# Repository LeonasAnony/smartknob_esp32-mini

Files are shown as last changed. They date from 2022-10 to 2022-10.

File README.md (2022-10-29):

# SmartKnob



SmartKnob is an open-source input device with software-configurable endstops and virtual detents. Original by [Scott Bezek](https://github.com/scottbez1/smartknob).

A brushless gimbal motor is paired with a magnetic encoder to provide closed-loop torque feedback control, making it
possible to dynamically create and adjust the feel of detents and endstops.

# Modifications
- ESP32-S3-MINI-1N8
- 24x WS2812 20x20 LED
- SMD Resistor 4 direction Force Sensor
- Accelerometer

# Handheld Version
Handheld Mod in branch [handheld](https://github.com/LeonasAnony/smartknob_esp32-mini/tree/handheld)

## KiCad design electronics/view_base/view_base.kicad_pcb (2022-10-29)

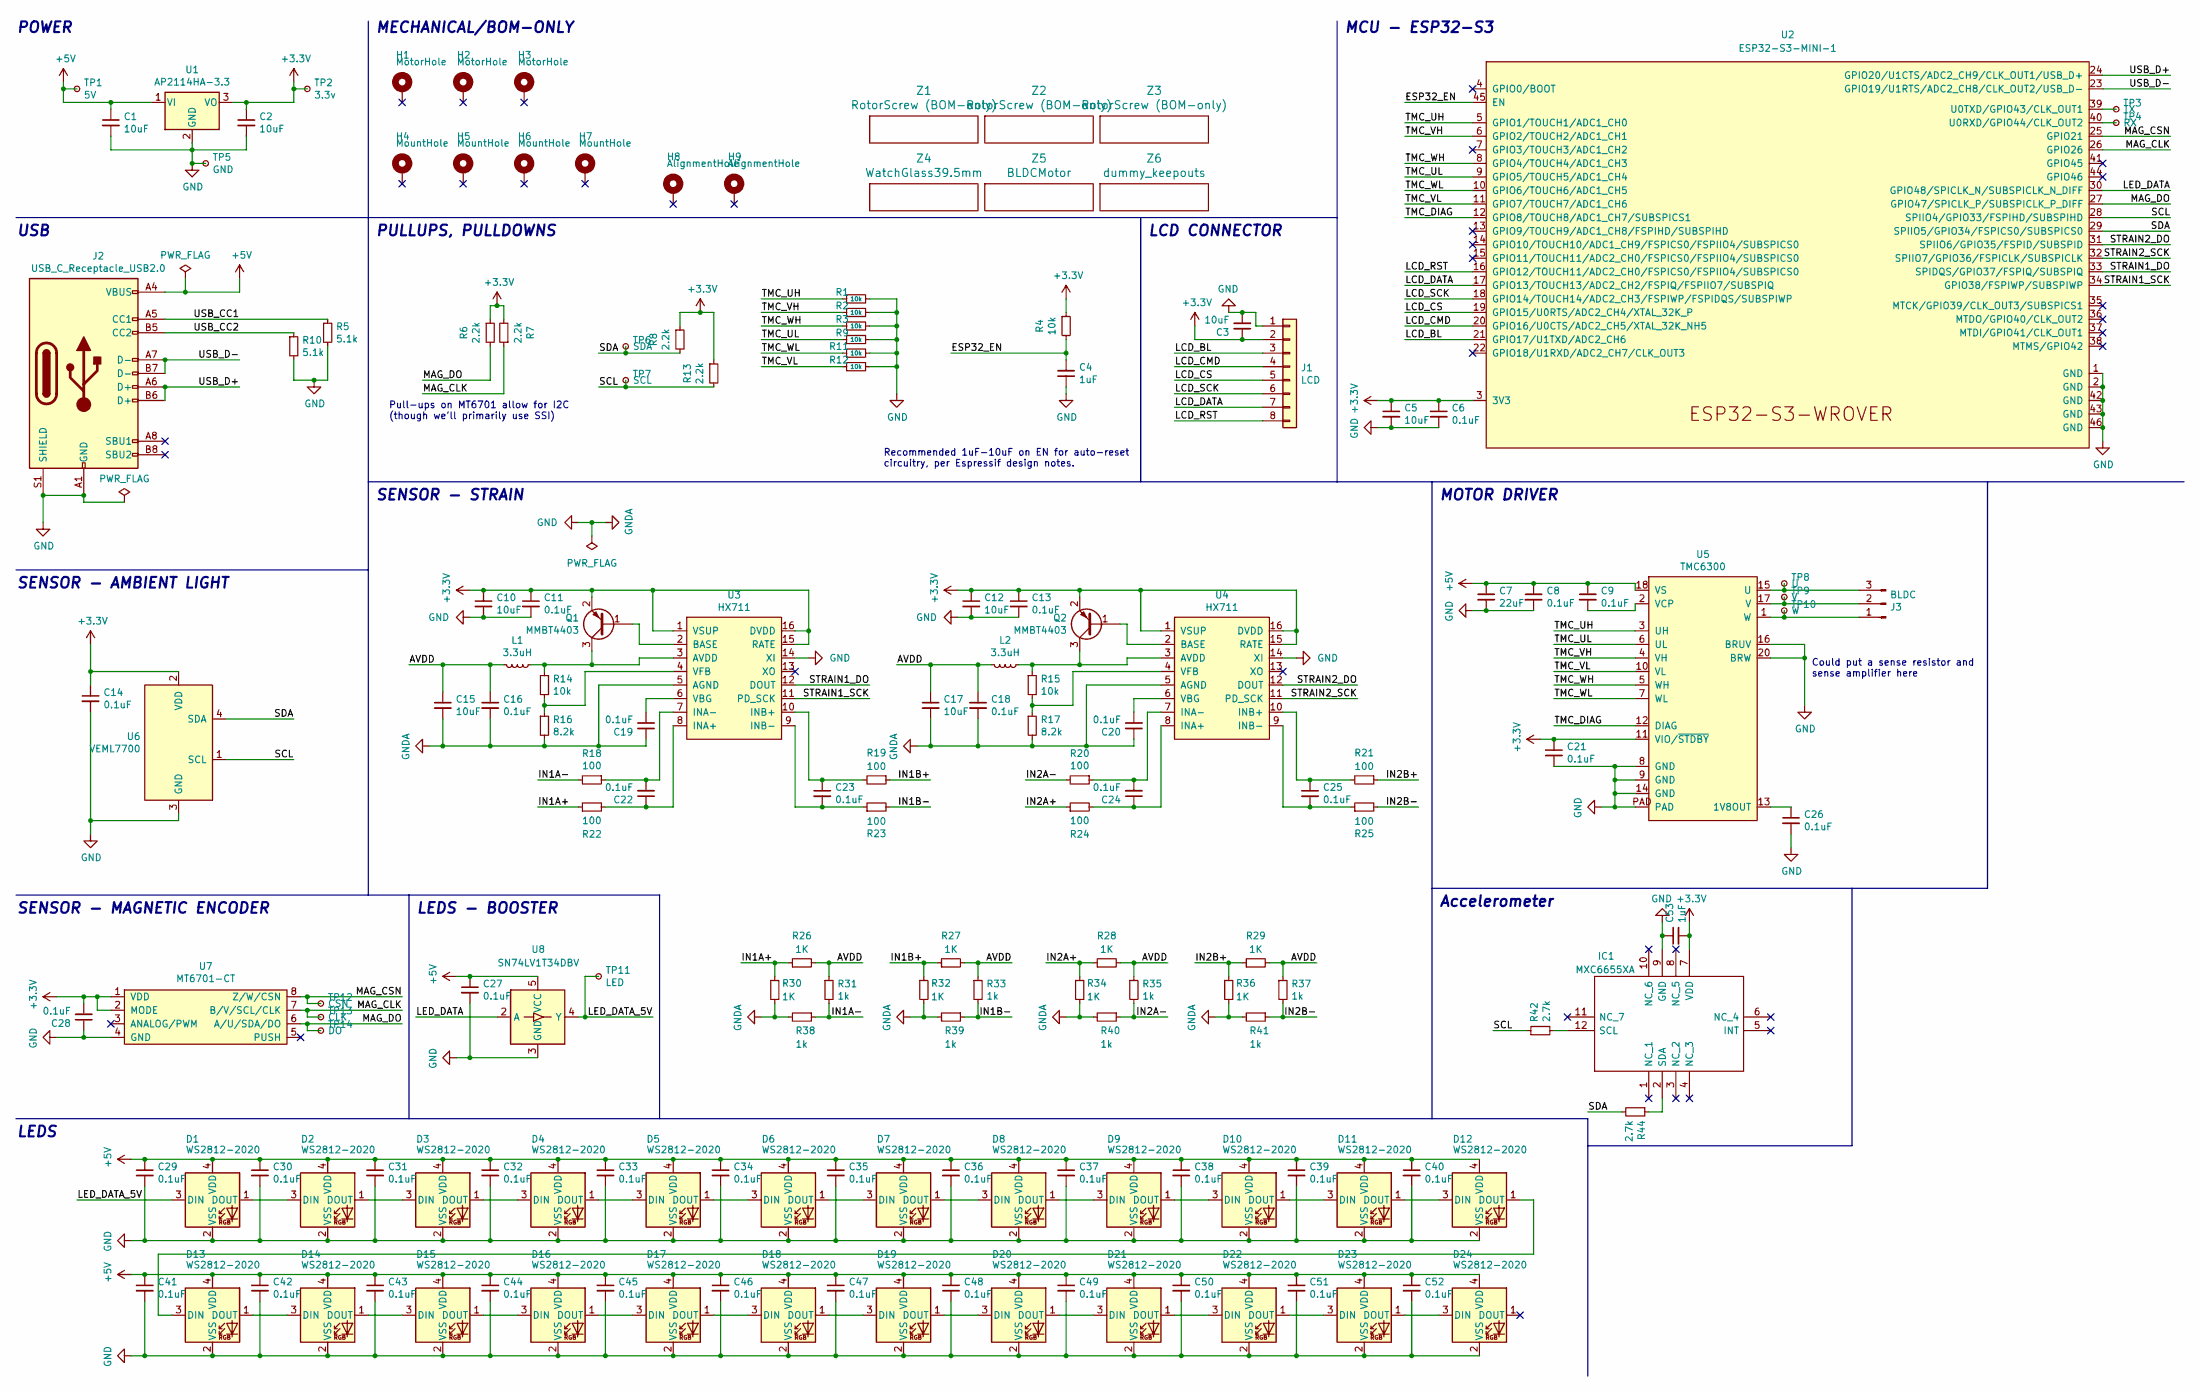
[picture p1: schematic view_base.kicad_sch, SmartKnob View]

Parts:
C1, C2, C3, C5, C10, C12, C15, C17: 10uF; C_0805_2012Metric; LCSC C2922480
C4: 1uF; C_0603_1608Metric; Mouser 187-CL10A105KA8NNNC
C6, C8, C9, C11, C13, C14, C16, C18, C19, C20, C21, C22, C23, C24, C25, C26, C27, C28, C29, C30, C31, C32, C33, C34, C35, C36, C37, C38, C39, C40, C41, C42, C43, C44, C45, C46, C47, C48, C49, C50, C51, C52: 0.1uF; C_0603_1608Metric; LCSC C1591
C7: 22uF; C_0805_2012Metric; LCSC C98190
C53: 1uF; C_0603_1608Metric; LCSC C1591
D1, D2, D3, D4, D5, D6, D7, D8, D9, D10, D11, D12, D13, D14, D15, D16, D17, D18, D19, D20, D21, D22, D23, D24: WS2812-2020; Digikey 1528-4691-ND
H1, H2, H3: MotorHole; MountingHole_M1.6
H4, H5, H6, H7: MountHole; MountingHole_2.2mm_M2_ISO7380_Pad_NonVirtual
H8, H9: AlignmentHole; MountingHole_2.2mm_M2_ISO7380_Pad_NonVirtual
IC1: MXC6655XA; Mouser Part Number 438-MXC6655XA
J1: LCD; SolderPads_2mm_8
J2: USB_C_Receptacle_USB2.0; USB4510_NoPaste; LCSC C428463
J3: BLDC; 532610371; LCSC C293630
L1, L2: 3.3uH; L_0805_2012Metric; LCSC C307744
Q1, Q2: MMBT4403; SOT-23; LCSC C78864
R1, R2, R3, R4, R9, R11, R12, R14, R15: 10k; R_0603_1608Metric; LCSC C98220
R5, R10: 5.1k; R_0603_1608Metric; LCSC C105580
R6, R7, R8, R13: 2.2k; R_0603_1608Metric; LCSC C4190
R16, R17: 8.2k; R_0603_1608Metric; LCSC C114637
R18, R19, R20, R21, R22, R23, R24, R25: 100; R_0603_1608Metric; LCSC C319953
R26, R27, R28, R29, R30, R32, R34, R36: 1K; R_2512_6332Metric
R31, R33, R35, R37, R38, R39, R40, R41: 1k; R_0603_1608Metric; LCSC C98220
R42, R44: 2.7k; R_0603_1608Metric; LCSC C98220
TP1: 5V; TestPoint_Pad_D2.0mm_ValueSilk
TP2: 3.3v; TestPoint_Pad_D2.0mm_ValueSilk
TP3: TX; TestPoint_Pad_D2.0mm_ValueSilk
TP4: RX; TestPoint_Pad_D2.0mm_ValueSilk
TP5: GND; TestPoint_Pad_D2.0mm_ValueSilk
TP6: SDA; TestPoint_Pad_D2.0mm_ValueSilk
TP7: SCL; TestPoint_Pad_D2.0mm_ValueSilk
TP8: U; TestPoint_Pad_D2.0mm_ValueSilk
TP9: V; TestPoint_Pad_D2.0mm_ValueSilk
TP10: W; TestPoint_Pad_D2.0mm_ValueSilk
TP11: LED; TestPoint_Pad_D2.0mm_ValueSilk
TP12: CSN; TestPoint_Pad_D2.0mm_ValueSilk
TP13: CLK; TestPoint_Pad_D2.0mm_ValueSilk
TP14: DO; TestPoint_Pad_D2.0mm_ValueSilk
U1: AP2114HA-3.3; SOT-223-3_TabPin2; LCSC C460314
U2: ESP32-S3-MINI-1
U3, U4: HX711; SOIC-16_3.9x9.9mm_P1.27mm; LCSC C43656
U5: TMC6300; QFN-20-1EP_3x3mm_P0.4mm_EP1.65x1.65mm_ThermalVias_LargerVia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; Digikey TMC6300-LA-T
U6: VEML7700; VEML7700-TOP; Digikey VEML7700-TT
U7: MT6701-CT; SOIC-8_3.9x4.9mm_P1.27mm; LCSC C2856764
U8: SN74LV1T34DBV; SOT-23-5; LCSC C100024
Z1, Z2, Z3: RotorScrew (BOM-only); bom_only_no_pin
Z4: WatchGlass39.5mm; bom_only_no_pin
Z5: BLDCMotor; bom_only_no_pin
Z6: dummy_keepouts; ViewKeepouts3d

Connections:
+3V3: C2.1, C3.1, C5.1, C6.1, C10.1, C11.1, C12.1, C13.1, C14.1, C21.1, C28.2, C53.2, IC1.7 (VDD), J1.2, Q1.2 (E), Q2.2 (E), R4.1, R6.1, R7.2, R8.1, R13.1, TP2.1, U1.3 (VO), U2.3 (3V3), U3.1 (VSUP), U3.15 (RATE), U3.16 (DVDD), U4.1 (VSUP), U4.15 (RATE), U4.16 (DVDD), U5.11 (VIO/~STDBY), U6.2 (VDD), U7.1 (VDD), U7.2 (MODE)
+5V: C1.1, C7.1, C8.1, C9.1, C27.1, C29.1, C30.1, C31.1, C32.1, C33.1, C34.1, C35.1, C36.1, C37.1, C38.1, C39.1, C40.1, C41.1, C42.1, C43.1, C44.1, C45.1, C46.1, C47.1, C48.1, C49.1, C50.1, C51.1, C52.1, D1.4 (VDD), D2.4 (VDD), D3.4 (VDD), D4.4 (VDD), D5.4 (VDD), D6.4 (VDD), D7.4 (VDD), D8.4 (VDD), D9.4 (VDD), D10.4 (VDD), D11.4 (VDD), D12.4 (VDD), D13.4 (VDD), D14.4 (VDD), D15.4 (VDD), D16.4 (VDD), D17.4 (VDD), D18.4 (VDD), D19.4 (VDD), D20.4 (VDD), D21.4 (VDD), D22.4 (VDD), D23.4 (VDD), D24.4 (VDD), J2.A4 (VBUS), J2.A9 (VBUS), J2.B4 (VBUS), J2.B9 (VBUS), TP1.1, U1.1 (VI), U5.18 (VS), U8.5 (VCC)
/ESP32_EN: C4.1, R4.2, U2.45 (EN)
/IN1A+: R22.1, R26.1, R30.1
/IN1A-: R18.2, R31.2, R38.1
/IN1B+: R19.1, R27.1, R32.1
/IN1B-: R23.2, R33.2, R39.1
/IN2A+: R24.1, R28.1, R34.1
/IN2A-: R20.2, R35.2, R40.1
/IN2B+: R21.1, R29.1, R36.1
/LCD_BL: J1.3, U2.21 (GPIO17/U1TXD/ADC2_CH6)
/LCD_CMD: J1.4, U2.20 (GPIO16/U0CTS/ADC2_CH5/XTAL_32K_NH5)
/LCD_CS: J1.5, U2.19 (GPIO15/U0RTS/ADC2_CH4/XTAL_32K_P)
/LCD_DATA: J1.7, U2.17 (GPIO13/TOUCH13/ADC2_CH2/FSPIQ/FSPIIO7/S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)
/LCD_RST: J1.8, U2.16 (GPIO12/TOUCH11/ADC2_CH0/FSPICS0/FSPIIO4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)
/LCD_SCK: J1.6, U2.18 (GPIO14/TOUCH14/ADC2_CH3/FSPIWP/FSPIDQS/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)
/LED_DATA: U2.30 (GPIO48/SPICLK_N/SUBSPICLK_N_DIFF), U8.2 (A)
/LED_DATA_5V: D1.3 (DIN), TP11.1, U8.4 (Y)
/MAG_CLK: R7.1, TP13.1, U2.26 (GPIO26), U7.7 (B/V/SCL/CLK)
/MAG_CSN: TP12.1, U2.25 (GPIO21), U7.8 (Z/W/CSN)
/MAG_DO: R6.2, TP14.1, U2.27 (GPIO47/SPICLK_P/SUBSPICLK_P_DIFF), U7.6 (A/U/SDA/DO)
/SCL: R13.2, R42.1, TP7.1, U2.28 (SPIIO4/GPIO33/FSPIHD/SUBSPIHD), U6.1 (SCL)
/SDA: R8.2, R44.2, TP6.1, U2.29 (SPIIO5/GPIO34/FSPICS0/SUBSPICS0), U6.4 (SDA)
/STRAIN1_DO: U2.33 (SPIDQS/GPIO37/FSPIQ/SUBSPIQ), U3.12 (DOUT)
/STRAIN1_SCK: U2.34 (GPIO38/FSPIWP/SUBSPIWP), U3.11 (PD_SCK)
/STRAIN2_DO: U2.31 (SPIIO6/GPIO35/FSPID/SUBSPID), U4.12 (DOUT)
/STRAIN2_SCK: U2.32 (SPIIO7/GPIO36/FSPICLK/SUBSPICLK), U4.11 (PD_SCK)
/TMC_DIAG: U2.12 (GPIO8/TOUCH8/ADC1_CH7/SUBSPICS1), U5.12 (DIAG)
/TMC_UH: R1.1, U2.5 (GPIO1/TOUCH1/ADC1_CH0), U5.3 (UH)
/TMC_UL: R9.1, U2.9 (GPIO5/TOUCH5/ADC1_CH4), U5.6 (UL)
/TMC_VH: R2.1, U2.6 (GPIO2/TOUCH2/ADC1_CH1), U5.4 (VH)
/TMC_VL: R12.1, U2.11 (GPIO7/TOUCH7/ADC1_CH6), U5.10 (VL)
/TMC_WH: R3.1, U2.8 (GPIO4/TOUCH4/ADC1_CH3), U5.5 (WH)
/TMC_WL: R11.1, U2.10 (GPIO6/TOUCH6/ADC1_CH5), U5.7 (WL)
/USB_CC1: J2.A5 (CC1), R5.1
/USB_CC2: J2.B5 (CC2), R10.1
/USB_D+: J2.A6 (D+), J2.B6 (D+), U2.24 (GPIO20/U1CTS/ADC2_CH9/CLK_OUT1/USB_D+)
/USB_D-: J2.A7 (D-), J2.B7 (D-), U2.23 (GPIO19/U1RTS/ADC2_CH8/CLK_OUT2/USB_D-)
GND: C1.2, C2.2, C3.2, C4.2, C5.2, C6.2, C7.2, C8.2, C10.2, C11.2, C12.2, C13.2, C14.2, C15.2, C16.2, C17.2, C18.2, C19.1, C20.1, C21.2, C26.2, C27.2, C28.1, C29.2, C30.2, C31.2, C32.2, C33.2, C34.2, C35.2, C36.2, C37.2, C38.2, C39.2, C40.2, C41.2, C42.2, C43.2, C44.2, C45.2, C46.2, C47.2, C48.2, C49.2, C50.2, C51.2, C52.2, C53.1, D1.2 (VSS), D2.2 (VSS), D3.2 (VSS), D4.2 (VSS), D5.2 (VSS), D6.2 (VSS), D7.2 (VSS), D8.2 (VSS), D9.2 (VSS), D10.2 (VSS), D11.2 (VSS), D12.2 (VSS), D13.2 (VSS), D14.2 (VSS), D15.2 (VSS), D16.2 (VSS), D17.2 (VSS), D18.2 (VSS), D19.2 (VSS), D20.2 (VSS), D21.2 (VSS), D22.2 (VSS), D23.2 (VSS), D24.2 (VSS), IC1.9 (GND), J1.1, J2.A1 (GND), J2.A12 (GND), J2.B1 (GND), J2.B12 (GND), J2.S1 (SHIELD), R1.2, R2.2, R3.2, R5.2, R9.2, R10.2, R11.2, R12.2, R16.2, R17.2, R30.2, R32.2, R34.2, R36.2, R38.2, R39.2, R40.2, R41.2, TP5.1, U1.2 (GND), U2.1 (GND), U2.2 (GND), U2.42 (GND), U2.43 (GND), U2.46 (GND), U3.5 (AGND), U3.14 (XI), U4.5 (AGND), U4.14 (XI), U5.8 (GND), U5.9 (GND), U5.14 (GND), U5.16 (BRUV), U5.20 (BRW), U5.PAD, U6.3 (GND), U7.4 (GND), U8.3 (GND)
unnamed: C9.2, U5.2 (VCP)
unnamed: C19.2, U3.6 (VBG)
unnamed: C20.2, U4.6 (VBG)
unnamed: C22.1, R22.2, U3.8 (INA+)
unnamed: C22.2, R18.1, U3.7 (INA-)
unnamed: C23.1, R19.2, U3.10 (INB+)
unnamed: C23.2, R23.1, U3.9 (INB-)
unnamed: C24.1, R24.2, U4.8 (INA+)
unnamed: C24.2, R20.1, U4.7 (INA-)
unnamed: C25.1, R21.2, U4.10 (INB+)
unnamed: C25.2, R25.1, U4.9 (INB-)
unnamed: C26.1, U5.13 (1V8OUT)
unnamed: D1.1 (DOUT), D2.3 (DIN)
unnamed: D2.1 (DOUT), D3.3 (DIN)
unnamed: D3.1 (DOUT), D4.3 (DIN)
unnamed: D4.1 (DOUT), D5.3 (DIN)
unnamed: D5.1 (DOUT), D6.3 (DIN)
unnamed: D6.1 (DOUT), D7.3 (DIN)
unnamed: D7.1 (DOUT), D8.3 (DIN)
unnamed: D8.1 (DOUT), D9.3 (DIN)
unnamed: D10.1 (DOUT), D11.3 (DIN)
unnamed: D9.1 (DOUT), D10.3 (DIN)
unnamed: D11.1 (DOUT), D12.3 (DIN)
unnamed: D12.1 (DOUT), D13.3 (DIN)
unnamed: D13.1 (DOUT), D14.3 (DIN)
unnamed: D14.1 (DOUT), D15.3 (DIN)
unnamed: D15.1 (DOUT), D16.3 (DIN)
unnamed: D16.1 (DOUT), D17.3 (DIN)
unnamed: D17.1 (DOUT), D18.3 (DIN)
unnamed: D18.1 (DOUT), D19.3 (DIN)
unnamed: D19.1 (DOUT), D20.3 (DIN)
unnamed: D20.1 (DOUT), D21.3 (DIN)
unnamed: D21.1 (DOUT), D22.3 (DIN)
unnamed: D22.1 (DOUT), D23.3 (DIN)
unnamed: D23.1 (DOUT), D24.3 (DIN)
unnamed: IC1.2 (SDA), R44.1
unnamed: IC1.12 (SCL), R42.2
unnamed: J3.1, TP10.1, U5.1 (W)
unnamed: J3.2, TP9.1, U5.17 (V)
unnamed: J3.3, TP8.1, U5.15 (U)
unnamed: L1.1, Q1.3 (C), R14.1, U3.3 (AVDD)
unnamed: L2.1, Q2.3 (C), R15.1, U4.3 (AVDD)
unnamed: Q1.1 (B), U3.2 (BASE)
unnamed: Q2.1 (B), U4.2 (BASE)
unnamed: R14.2, R16.1, U3.4 (VFB)
unnamed: R15.2, R17.1, U4.4 (VFB)
unnamed: TP3.1, U2.39 (U0TXD/GPIO43/CLK_OUT1)
unnamed: TP4.1, U2.40 (U0RXD/GPIO44/CLK_OUT2)

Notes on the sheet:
SENSOR - STRAIN
MECHANICAL/BOM-ONLY
Accelerometer
MCU - ESP32-S3
LEDS
PULLUPS, PULLDOWNS
Could put a sense resistor and sense amplifier here
MOTOR DRIVER
Recommended 1uF-10uF on EN for auto-reset circuitry, per Espressif design notes.
POWER
SENSOR - AMBIENT LIGHT
LEDS - BOOSTER
SENSOR - MAGNETIC ENCODER
Pull-ups on MT6701 allow for I2C (though we'll primarily use SSI)
USB
LCD CONNECTOR

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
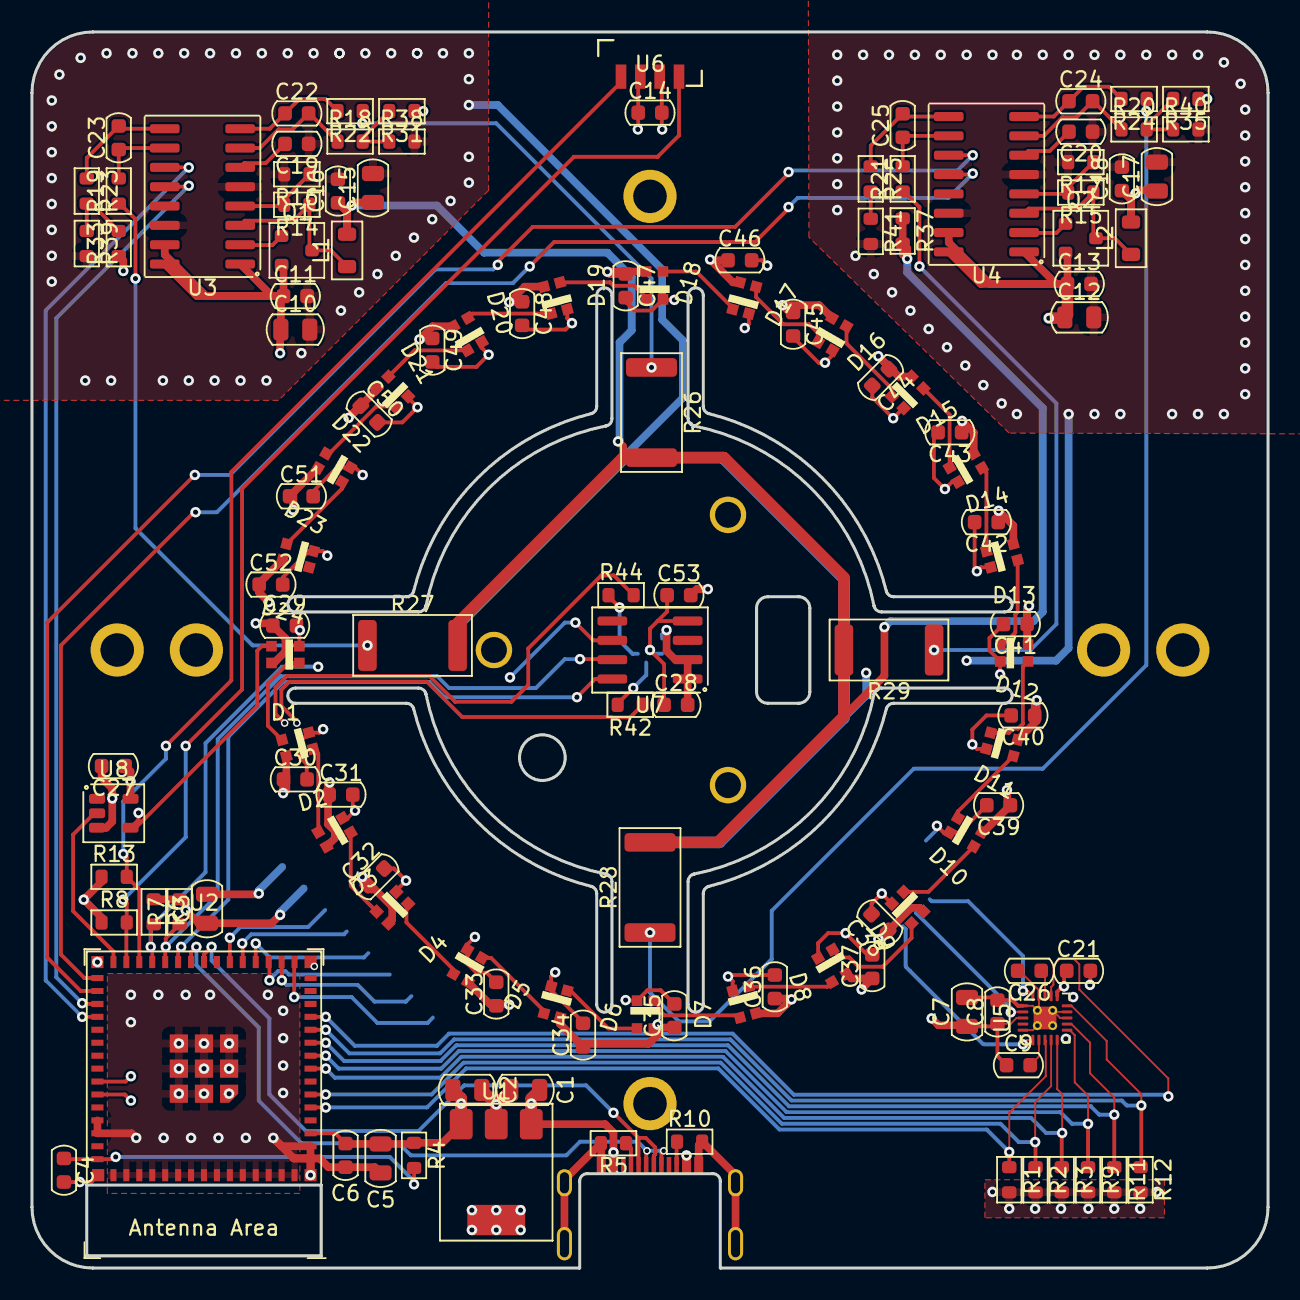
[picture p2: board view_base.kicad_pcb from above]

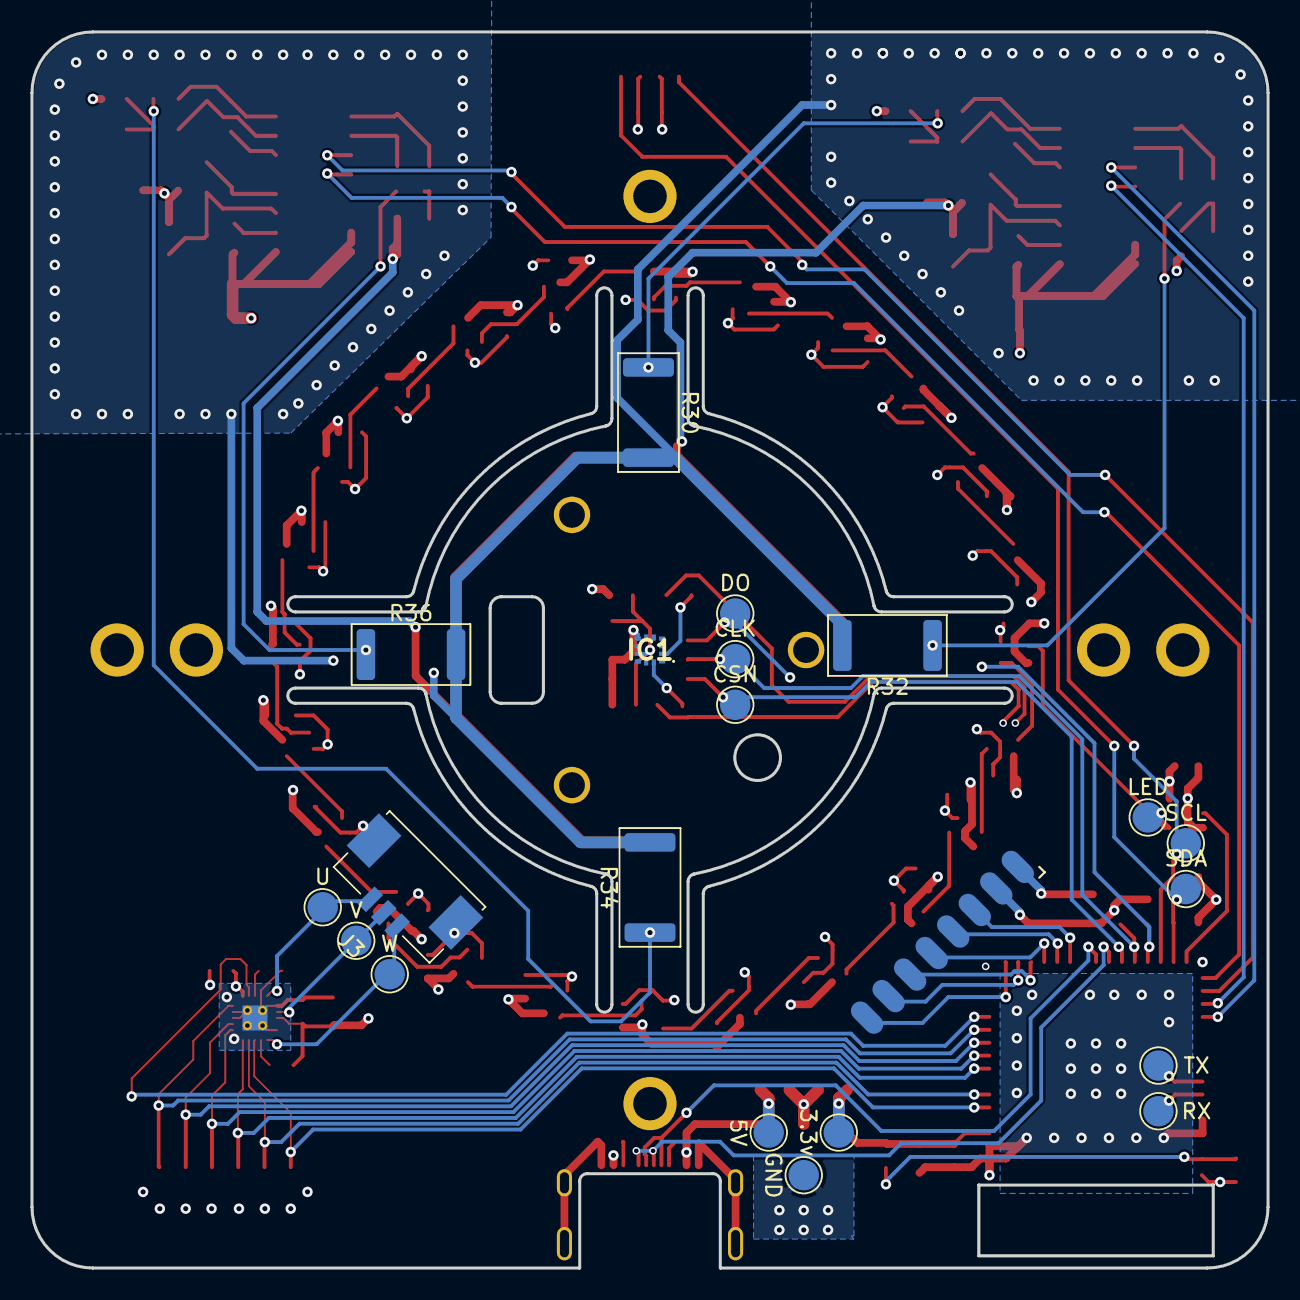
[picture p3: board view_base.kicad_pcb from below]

Board: 4 copper layers, 81.2 x 81.2 mm, 165 parts (21 on the bottom side), 89 nets.

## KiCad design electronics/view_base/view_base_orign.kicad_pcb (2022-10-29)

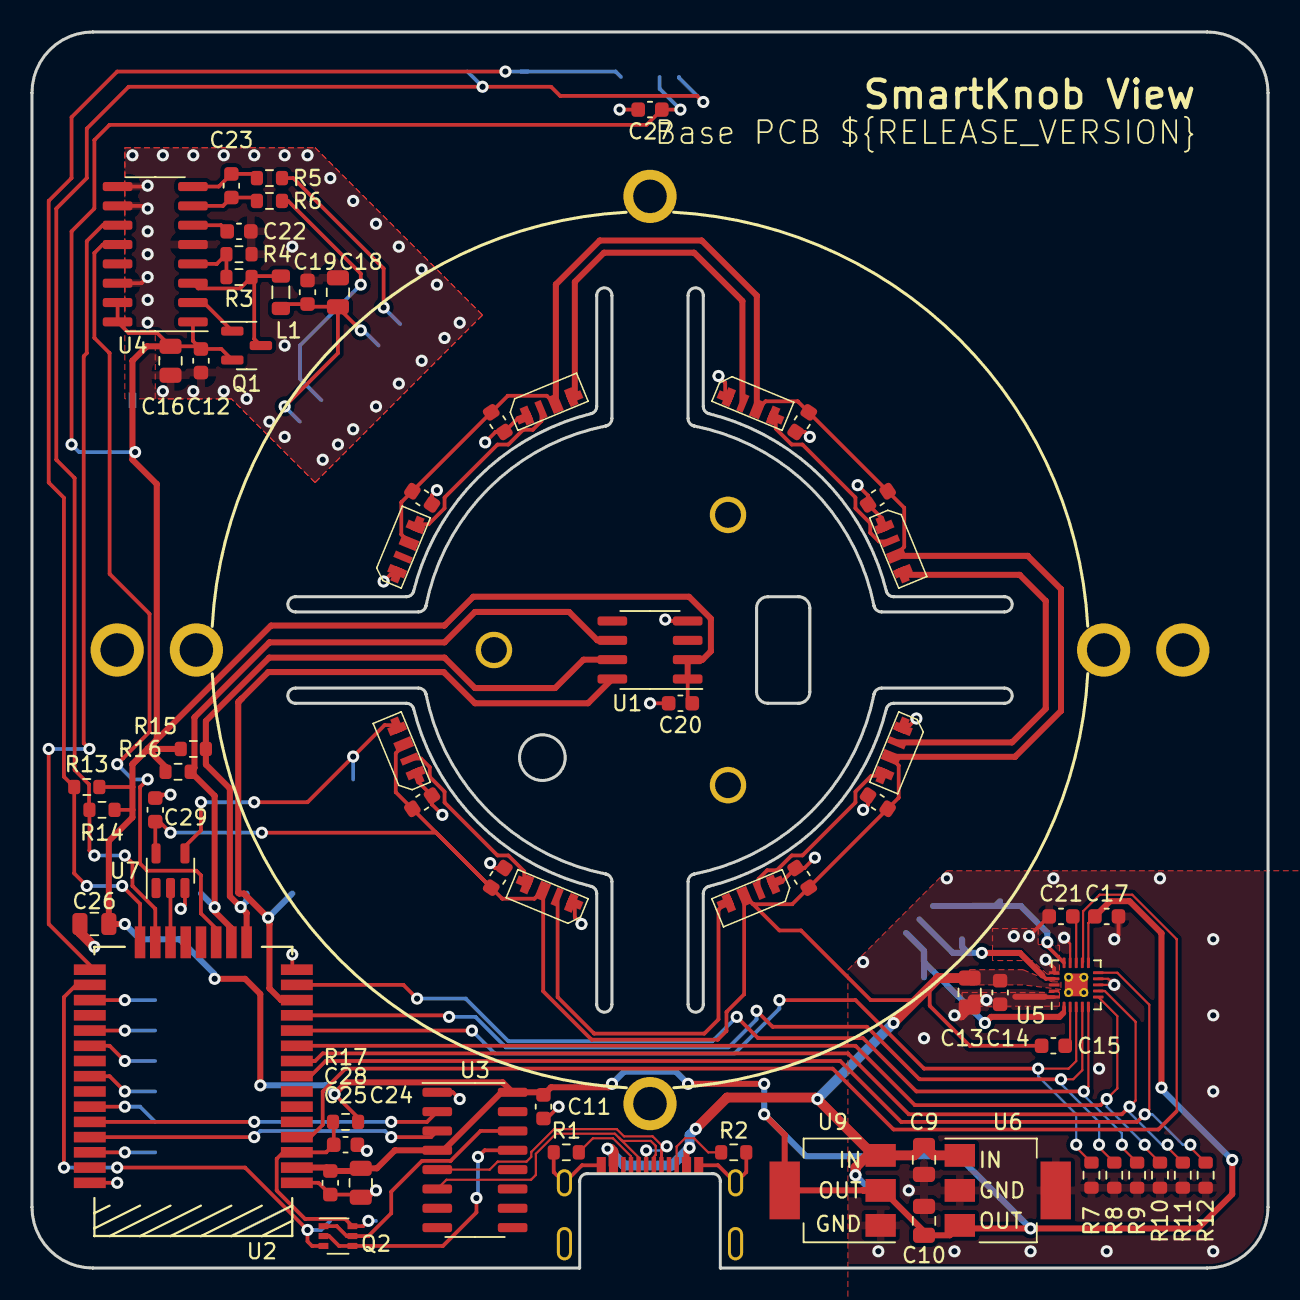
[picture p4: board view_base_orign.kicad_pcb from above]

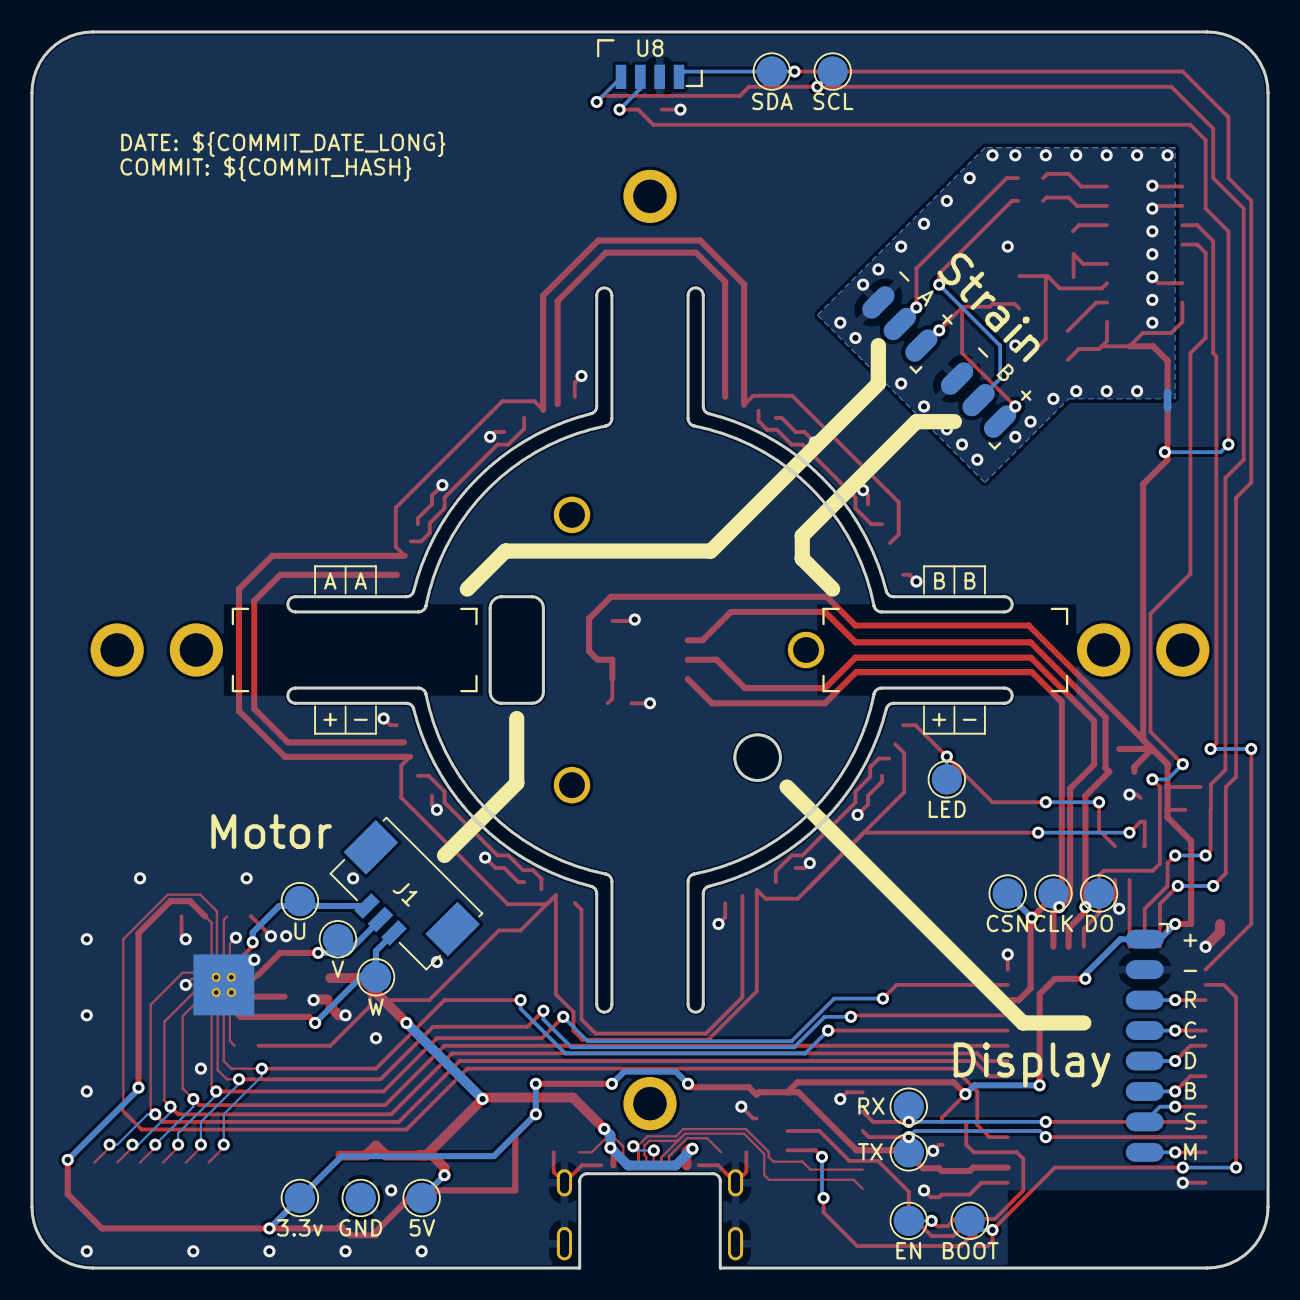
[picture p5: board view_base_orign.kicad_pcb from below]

Board: 2 copper layers, 81.2 x 81.2 mm, 107 parts (26 on the bottom side), 57 nets.

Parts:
C1, C2, C3, C4, C5, C6, C7, C8, C11, C12, C14, C15, C17, C19, C20, C21, C22, C23, C25, C27, C29: 0.1uF; C_0603_1608Metric
C9, C10, C16, C18, C24, C26: 10uF; C_0805_2012Metric
C13: 22uF; C_0805_2012Metric
C28: 1uF; C_0603_1608Metric
D1, D2, D3, D4, D5, D6, D7, D8: SK6812SIDE-A; SK6812-SIDE-A
H1, H2, H3: MotorHole; MountingHole_M1.6
H4, H5, H6, H7: MountHole; MountingHole_2.2mm_M2_ISO7380_Pad_NonVirtual
H8, H9: AlignmentHole; MountingHole_2.2mm_M2_ISO7380_Pad_NonVirtual
J1: BLDC; 532610371
J2: USB_C_Receptacle_USB2.0; USB4510_NoPaste
J3: LCD; SolderPads_2mm_8
J4: A; SolderPads_2mm_3_STRAIN
J5: B; SolderPads_2mm_3_STRAIN
L1: 3.3uH; L_0805_2012Metric
NT1: NetTie_2; NetTie-2_SMD_Pad0.5mm
Q1: MMBT4403; SOT-23
Q2: UMH3N; SOT-363_SC-70-6
R1, R2: 5.1k; R_0603_1608Metric
R3, R7, R8, R9, R10, R11, R12, R17: 10k; R_0603_1608Metric
R4: 8.2k; R_0603_1608Metric
R5, R6: 100; R_0603_1608Metric
R13, R14, R15, R16: 2.2k; R_0603_1608Metric
TP1: 5V; TestPoint_Pad_D2.0mm_ValueSilk
TP2: 3.3v; TestPoint_Pad_D2.0mm_ValueSilk
TP3: GND; TestPoint_Pad_D2.0mm_ValueSilk
TP4: SDA; TestPoint_Pad_D2.0mm_ValueSilk
TP5: SCL; TestPoint_Pad_D2.0mm_ValueSilk
TP6: U; TestPoint_Pad_D2.0mm_ValueSilk
TP7: V; TestPoint_Pad_D2.0mm_ValueSilk
TP8: W; TestPoint_Pad_D2.0mm_ValueSilk
TP9: CSN; TestPoint_Pad_D2.0mm_ValueSilk
TP10: CLK; TestPoint_Pad_D2.0mm_ValueSilk
TP11: DO; TestPoint_Pad_D2.0mm_ValueSilk
TP12: LED; TestPoint_Pad_D2.0mm_ValueSilk
TP13: EN; TestPoint_Pad_D2.0mm_ValueSilk
TP14: BOOT; TestPoint_Pad_D2.0mm_ValueSilk
TP15: TX; TestPoint_Pad_D2.0mm_ValueSilk
TP16: RX; TestPoint_Pad_D2.0mm_ValueSilk
U1: MT6701-CT; SOIC-8_3.9x4.9mm_P1.27mm
U2: T-Micro32_Plus; T-Micro32
U3: CH340C; SOIC-16_3.9x9.9mm_P1.27mm
U4: HX711; SOIC-16_3.9x9.9mm_P1.27mm
U5: TMC6300; QFN-20-1EP_3x3mm_P0.4mm_EP1.65x1.65mm_ThermalVias_LargerVia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
U6: AP2114HA-3.3; SOT-223-3_TabPin2_InGndOut
U7: SN74LV1T34DBV; SOT-23-5
U8: VEML7700; VEML7700-TOP
U9: TS1117BCW33_RPG; SOT-223-3_TabPin2_GndOutIn
Z1, Z2, Z3, Z4: BF350-3AA Strain Gauge; BF350-3AA
Z5: dummy_keepouts; ViewKeepouts3d
Z6, Z7, Z8: RotorScrew (BOM-only); bom_only_no_pin
Z9: WatchGlass39.5mm; bom_only_no_pin
Z10: BLDCMotor; bom_only_no_pin

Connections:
+3V3: C10.1, C11.1, C12.1, C16.1, C17.1, C20.1, C24.1, C25.1, C26.1, C27.1, J3.1, Q1.2 (E), R13.1, R14.1, R15.1, R16.2, R17.1, TP2.1, U1.1 (VDD), U1.2 (MODE), U2.2 (3V3), U3.4 (V3), U3.16 (VCC), U4.1 (VSUP), U4.15 (RATE), U4.16 (DVDD), U5.11 (VIO/~STDBY), U6.3 (VO), U8.2 (VDD), U9.2 (Output)
+5V: C1.1, C2.1, C3.1, C4.1, C5.1, C6.1, C7.1, C8.1, C9.1, C13.1, C14.1, C15.1, C29.1, D1.2 (VDD), D2.2 (VDD), D3.2 (VDD), D4.2 (VDD), D5.2 (VDD), D6.2 (VDD), D7.2 (VDD), D8.2 (VDD), J2.A4 (VBUS), J2.A9 (VBUS), J2.B4 (VBUS), J2.B9 (VBUS), TP1.1, U5.18 (VS), U6.1 (VI), U7.5 (VCC), U9.3 (Input)
/DTR: Q2.2 (B1), Q2.4 (E2), U3.13 (~DTR)
/ESP32_BOOT: Q2.3 (C2), TP14.1, U2.25 (IO0)
/ESP32_EN: C28.1, Q2.6 (C1), R17.2, TP13.1, U2.3 (EN)
/LCD_BACKLIGHT: J3.6, U2.31 (IO19)
/LCD_CMD: J3.8, U2.36 (IO22)
/LCD_CS: J3.7, U2.33 (IO21)
/LCD_DATA: J3.5, U2.29 (IO5)
/LCD_RST: J3.3, U2.26 (IO4)
/LCD_SCK: J3.4, U2.28 (IO20)
/LED_DATA_3V3: U2.21 (IO7), U7.2 (A)
/LED_DATA_5V: D1.1 (DIN), TP12.1, U7.4 (Y)
/MAG_CLK: R16.1, TP10.1, U1.7 (B/V/SCL/CLK), U2.16 (IO13)
/MAG_CSN: TP9.1, U1.8 (Z/W/CSN), U2.13 (IO14)
/MAG_DO: R15.2, TP11.1, U1.6 (A/U/SDA/DO), U2.17 (IO37)
/RTS: Q2.1 (E1), Q2.5 (B2), U3.14 (~RTS)
/SCL: R14.2, TP5.1, U2.22 (IO8), U8.1 (SCL)
/SDA: R13.2, TP4.1, U2.23 (IO15), U8.4 (SDA)
/STRAIN_DO: U2.18 (IO38), U4.12 (DOUT)
/STRAIN_E+: C18.1, C19.1, J4.1, J5.1, L1.2
/STRAIN_S+: J4.2, R6.1
/STRAIN_S-: J5.2, R5.2
/STRAIN_SCK: U2.24 (IO2), U4.11 (PD_SCK)
/TMC_DIAG: U2.4 (IO36/SVP), U5.12 (DIAG)
/TMC_UH: R7.1, U2.11 (IO26), U5.3 (UH)
/TMC_UL: R10.1, U2.10 (IO25), U5.6 (UL)
/TMC_VH: R8.1, U2.12 (IO27), U5.4 (VH)
/TMC_VL: R12.1, U2.8 (IO32), U5.10 (VL)
/TMC_WH: R9.1, U2.14 (IO12), U5.5 (WH)
/TMC_WL: R11.1, U2.9 (IO33), U5.7 (WL)
/USB_CC1: J2.A5 (CC1), R1.1
/USB_CC2: J2.B5 (CC2), R2.1
/USB_D+: J2.A6 (D+), J2.B6 (D+), U3.5 (UD+)
/USB_D-: J2.A7 (D-), J2.B7 (D-), U3.6 (UD-)
/USB_SERIAL_RXI: TP15.1, U2.35 (TXD), U3.3 (RXD)
/USB_SERIAL_TXO: TP16.1, U2.34 (RXD), U3.2 (TXD)
GND: C1.2, C2.2, C3.2, C4.2, C5.2, C6.2, C7.2, C8.2, C9.2, C10.2, C11.2, C13.2, C14.2, C17.2, C20.2, C21.2, C24.2, C25.2, C26.2, C27.2, C28.2, C29.2, D1.4 (VSS), D2.4 (VSS), D3.4 (VSS), D4.4 (VSS), D5.4 (VSS), D6.4 (VSS), D7.4 (VSS), D8.4 (VSS), J2.A1 (GND), J2.A12 (GND), J2.B1 (GND), J2.B12 (GND), J2.S1 (SHIELD), J3.2, NT1.2, R1.2, R2.2, R7.2, R8.2, R9.2, R10.2, R11.2, R12.2, TP3.1, U1.4 (GND), U2.1 (GND), U2.15 (GND), U2.38 (GND), U3.1 (GND), U5.8 (GND), U5.9 (GND), U5.14 (GND), U5.16 (BRUV), U5.20 (BRW), U5.PAD, U6.2 (GND), U7.3 (GND), U8.3 (GND), U9.1 (GND)
GNDA: C12.2, C16.2, C18.2, C19.2, C22.1, J4.3, J5.3, NT1.1, R4.2, U4.5 (AGND), U4.9 (INB-), U4.10 (INB+), U4.14 (XI)
unnamed: C15.2, U5.2 (VCP)
unnamed: C21.1, U5.13 (1V8OUT)
unnamed: C22.2, U4.6 (VBG)
unnamed: C23.1, R6.2, U4.8 (INA+)
unnamed: C23.2, R5.1, U4.7 (INA-)
unnamed: D1.3 (DOUT), D2.1 (DIN)
unnamed: D2.3 (DOUT), D3.1 (DIN)
unnamed: D3.3 (DOUT), D4.1 (DIN)
unnamed: D4.3 (DOUT), D5.1 (DIN)
unnamed: D5.3 (DOUT), D6.1 (DIN)
unnamed: D6.3 (DOUT), D7.1 (DIN)
unnamed: D7.3 (DOUT), D8.1 (DIN)
unnamed: J1.1, TP8.1, U5.1 (W)
unnamed: J1.2, TP7.1, U5.17 (V)
unnamed: J1.3, TP6.1, U5.15 (U)
unnamed: L1.1, Q1.3 (C), R3.1, U4.3 (AVDD)
unnamed: Q1.1 (B), U4.2 (BASE)
unnamed: R3.2, R4.1, U4.4 (VFB)

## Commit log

2022-10-29 Mod v1
    - ESP32-S3-MINI-1N8
    - 24x WS2812 20x20 LED
    - SMD Resistors 4 direction Force Sensor
    - Accelerometer
    [view_base-B_Cu.gbr, view_base-B_Mask.gbr, view_base-B_Paste.gbr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]
2022-10-29 Gerbers for Release
    [view_screen-B_Cu.gbl, view_screen-B_Mask.gbs, view_screen-B_Paste.gbp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]

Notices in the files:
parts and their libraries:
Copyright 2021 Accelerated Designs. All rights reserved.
